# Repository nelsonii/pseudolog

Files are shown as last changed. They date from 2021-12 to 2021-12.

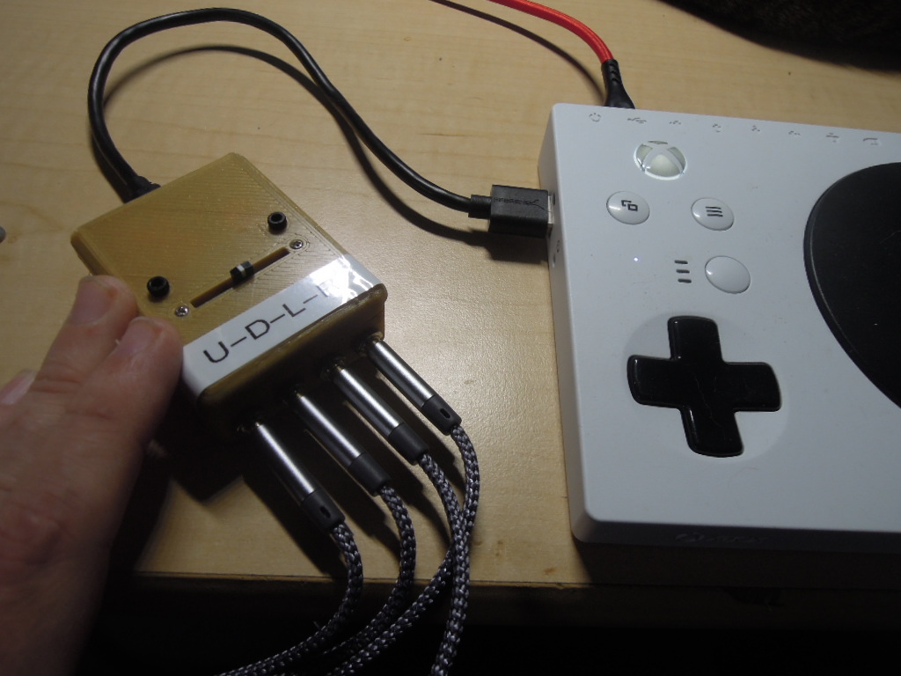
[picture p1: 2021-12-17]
DSCN8653.JPG

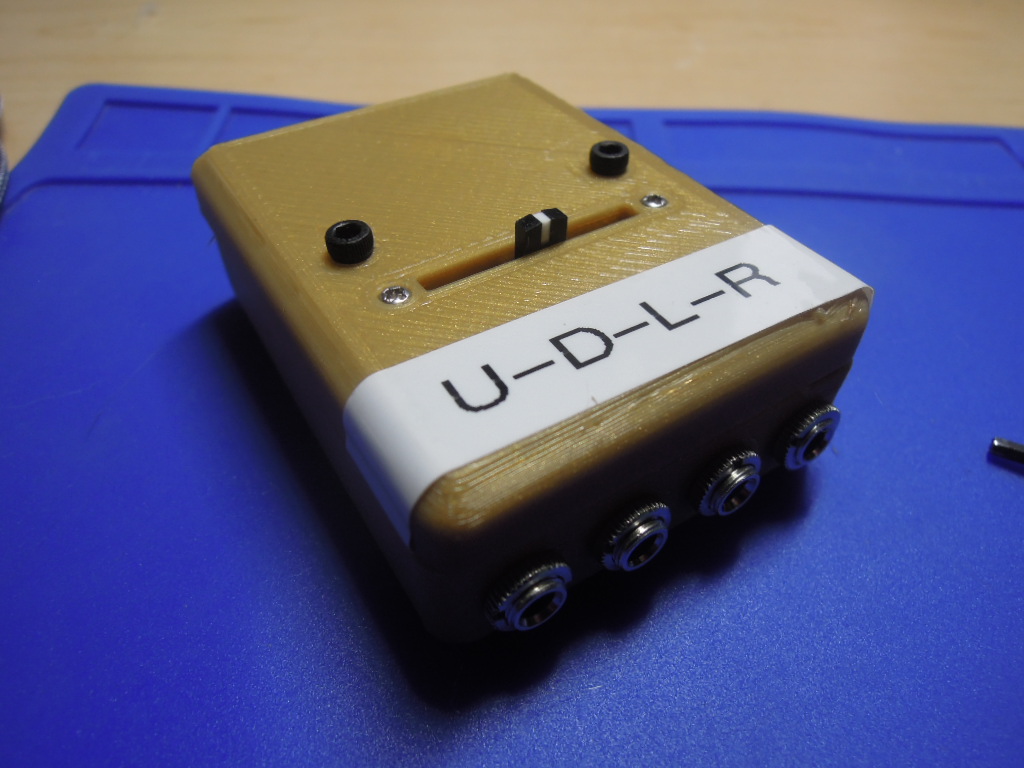
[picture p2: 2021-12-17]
DSCN8651.JPG

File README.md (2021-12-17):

# pseudolog
An Arduino based adapter which converts digital on/off button action to pseudo analog joystick commands.

3D model is in OpenSCAD. If you just want to print the STLs, use the latest verion (alpha order). _TOP should be flipped Y 180 degrees in your slicer.
No supports needed. The cutout circles will print fine.

Sized for an Arduino Pro Micro (Leo). Will also fit a QT PY.

Four jacks get wired to the analog pins. Sensitivity pot to another analog pin. Common power goes to jacks. Common power and Ground go to slide pot. Wiper on slide pot goes to analog pin.

While I'm working on proper schematics, here's the wiring:

Up > A0 (gray wire)
Down > A1 (purple wire)
Left > A2 (orange wire)
Right > A3 (brown wire)

(colors don't matter, but that's what in my photos)

Slide Pot is tied to A10. Slide pot also needs VCC and GND. VCC to pin 1 on pot, GND to pin 3 on pot, A10/signal/wiper to pin 2 on pot.

NeoPixel (optional) tied to pin 6. (Code not yet written.) Also needs VCC and GND.

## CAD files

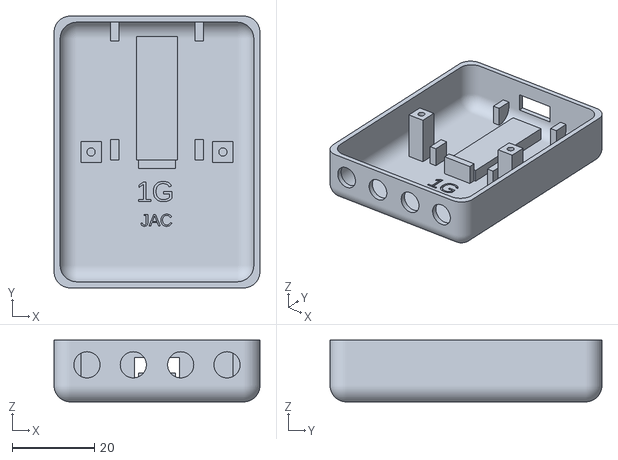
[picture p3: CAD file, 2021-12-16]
SwitchPseudolog_v1G_BOT.stl
50.0 x 66.0 x 15.0

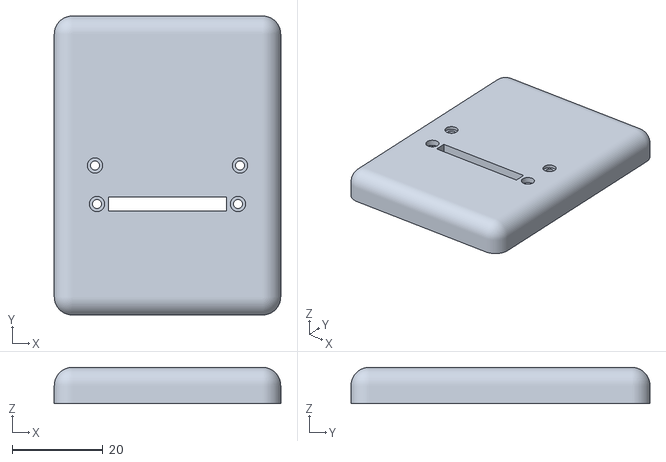
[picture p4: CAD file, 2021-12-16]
SwitchPseudolog_v1E_TOP.stl
50.0 x 66.0 x 8.01

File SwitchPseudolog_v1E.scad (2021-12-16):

include <BOSL/constants.scad>
use <BOSL/shapes.scad>

fileVersion = "1E";

caseWidthX = 50;
caseDepthY = 66;
caseHeightZ = 24;
wallThickness = 3;
overlap = 1; // overlap ensures that subtractions go beyond the edges

includeComponents = false; // optional component models, usually not included in print
  
mountingScrewDiameter = 2.0; // M2 Screw
mountingScrewHeadDiameter = 3.4; // M2 Phillips Head Screw
mountingScrewHeadHeight = 1.6; // M2 Phillips Head Screw

//joyType = "JST6";
//joyType = "DB9";
joyType = "JAC";

emboss = true;
  
$fn=60; //circle smoothness
  
difference(){
  union() {
    difference(){
      //base
      //rounded cuboid is from the BOSL library
      //I'm using p1 setting to zero bottom (z). X/Y are centered on 0,0,0
      color("steelblue")
      cuboid([caseWidthX,caseDepthY,caseHeightZ], fillet=4, 
       p1=[-(caseWidthX/2), -(caseDepthY/2), 0]);
      //subtract out the inner cuboid
      cuboid([caseWidthX-wallThickness,caseDepthY-wallThickness,caseHeightZ-wallThickness], fillet=4, 
       p1=[-((caseWidthX-wallThickness)/2), -((caseDepthY-wallThickness)/2), (wallThickness/2)]);
      if (emboss) {
        //emboss version on inside case
        color("whitesmoke")
         translate([-5, -12, 1])
          linear_extrude(2)
           text(fileVersion, size=5);
        color("whitesmoke")
         translate([-4,-18, 1])
          linear_extrude(2)
           text(joyType, size=3);
        /*
        //emboss port info on outside of case
        color("whitesmoke")
         translate([-7, 25, caseHeightZ - 1]) 
          linear_extrude(2)
           text("USB", size=5);
        color("whitesmoke")
         translate([-20, -28, caseHeightZ - 1]) 
          linear_extrude(2)
           text("U    D    L    R", size=5);
        */
      }
    }//difference (base)

    //riser for micro pro board
    color("purple")
     translate([-5,-2,0])
      cube([10, 30, 5]);
   
    if (joyType=="JST6") {
    //riser for joystick connector (additional support)
    color("darkmagenta")
    translate([-((caseWidthX-wallThickness)/2), 5, 1]) 
        cube([7, 17.5, 4]);
    }
    
    if (joyType=="JAC") {
    //riser for slide pot (additional support)
    color("hotpink")
    translate([-18, -12.5, caseHeightZ-wallThickness-4]) 
        cube([36, 8.25, 6]);
    }
    
    //bumper for micro pro board -- endstop
    color("violet")
     translate([-4.5, -4, 0])  
      cube([9, 2, 7]);
    //bumpers for micro pro board -- lower side
    color("violet")
     translate([-11.25, -2, 0]) 
      cube([2,5,7]);
    color("violet")
     translate([9.25, -2, 0]) 
      cube([2,5,7]);
    //bumpers for micro pro board -- upper side
    color("violet")
     translate([-11.25, 27, 1.5]) 
      cube([2,5,5.5]);
    color("violet")
     translate([9.25, 27, 1.5]) 
      cube([2,5,5.5]);
    
    //case screw mounts
    color("gold")
     translate([-16-2.5, -2.5, 0])
      cube([5,5,caseHeightZ]);
    color("gold")
     translate([+16-2.5, -2.5, 0])
      cube([5,5,caseHeightZ]);

    if (includeComponents) {
      if (joyType=="JST6") {
        //model of connector to joystick
        color("tan")
         translate([-10, -5, 6]) 
          cube([6,18,10]);
      }        
    }//includeComponents
    
  }//union
  
  // Start of Difference stuff ************************************************************

  //USB Micro cable outlet -- chunky cord is 11mm wide and 7mm high.
  color("coral")
   translate([-5.5,30,5.75])
    cube([11, (wallThickness*2), 5]);


  if (joyType=="JST6") {
    //joystick connector
    color("darkorange")
    translate([-((caseWidthX+wallThickness)/2), 5, 5.1]) 
          cube([wallThickness*2, 17.5, 7.0]); 
  }
  if (joyType=="DB9") {
    //joystick connector
    color("darkorange")
    translate([-19.2/2, -((caseDepthY+wallThickness)/2), 5.1]) 
          cube([19.2, wallThickness*2, 10.7]); 
  }


  if (joyType=="JAC") {
    //four switch joystick connection
    color("darkorange")
     translate([-15, -((caseDepthY+wallThickness)/2), 9]) 
      rotate([-90,0,0])
          cylinder(h=wallThickness*2, d=6); 
    color("darkorange")
     translate([+15, -((caseDepthY+wallThickness)/2), 9]) 
      rotate([-90,0,0])
          cylinder(h=wallThickness*2, d=6); 
    color("darkorange")
     translate([-5, -((caseDepthY+wallThickness)/2), 9]) 
      rotate([-90,0,0])
          cylinder(h=wallThickness*2, d=6); 
    color("darkorange")
     translate([+5, -((caseDepthY+wallThickness)/2), 9]) 
      rotate([-90,0,0])
          cylinder(h=wallThickness*2, d=6); 
  }      

if (joyType=="JAC") {
  //slide pot cutout
  color("pink")
   translate([-13, -10, caseHeightZ-wallThickness-5])
    cube([26, 3, wallThickness+overlap+5]);
  //mounting screws
  color("deeppink")
   translate([-15.565, -8.5, caseHeightZ-wallThickness-5])
    cylinder(h=wallThickness+overlap+5, d=2);
  color("deeppink")
   translate([+15.565, -8.5, caseHeightZ-wallThickness-5])
    cylinder(h=wallThickness+overlap+5, d=2);
  //countersinks
  color("hotpink")
   translate([-15.565, -8.5, caseHeightZ-1.5])
    cylinder(h=2+overlap, d=3.4);
  color("hotpink")
   translate([+15.565, -8.5, caseHeightZ-1.5])
    cylinder(h=2+overlap, d=3.4);
}


  //screw hole for case (goes through top of case)
  color("tomato")
   translate([-16, 0, wallThickness])
    cylinder(h=caseHeightZ+overlap, d=mountingScrewDiameter);
  color("tomato")
   translate([+16, -0, wallThickness])
    cylinder(h=caseHeightZ+overlap, d=mountingScrewDiameter);
  
  //countersink
  color("darkorange")
   translate([-16, 0, caseHeightZ-(mountingScrewHeadHeight/2)])
    cylinder(h=mountingScrewHeadHeight+overlap, d=mountingScrewHeadDiameter);
  color("darkorange")
   translate([+16, -0, caseHeightZ-(mountingScrewHeadHeight/2)])  
    cylinder(h=mountingScrewHeadHeight+overlap, d=mountingScrewHeadDiameter);
 
  //-------------------------------------------------------------------------------------------------------

  splitAtZ=15; //actual top of usb opening is 10.75
  
  //remove the top for split
  color("crimson")  translate([-((caseWidthX+overlap)/2),-((caseDepthY+overlap)/2),splitAtZ])  cube([caseWidthX+overlap, caseDepthY+overlap, caseHeightZ+overlap]);
  // ******* OR ******
  //Remove everything but the top
  //color("crimson") translate([-((caseWidthX+overlap)/2),-((caseDepthY+overlap)/2),splitAtZ-caseHeightZ])  cube([caseWidthX+overlap, caseDepthY+overlap, caseHeightZ+overlap]);

  //-------------------------------------------------------------------------------------------------------
  
  
}//difference
  

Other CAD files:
SwitchPseudolog_v1G_TOP.stl
SwitchPseudolog_v1E_BOT.stl
SwitchPseudolog_v1F.scad
SwitchPseudolog_v1G.scad

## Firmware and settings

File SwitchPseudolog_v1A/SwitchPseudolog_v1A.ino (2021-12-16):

//SwitchPseudoLog_v1A

//=================================================================================

#include "Joystick.h"

//=================================================================================

Joystick_ Joystick(JOYSTICK_DEFAULT_REPORT_ID, 
                   JOYSTICK_TYPE_JOYSTICK, 0, 0,
                   true, true, false, false, false, false,
                   false, false, false, false, false);

// constructor: use default id, it's a joystick, there are no buttons,
//              there are no hat buttons, there is an X and Y analog
//              and no other controls.

//=================================================================================

const boolean debug = false; // if true, output info to serial monitor or plotter.
const boolean debugVerbose = false; // if true, output more info to serial monitor.
const boolean debugPlot = false; // if true, output data for plotter/graph viewing.

//=================================================================================

// Joystick pins
#define SW_UP A0
#define SW_DN A1  
#define SW_LT A2
#define SW_RT A3

//pot for adjusting sensitivity
#define SENSE A10

//=================================================================================

// values from switches
long rawLT, rawRT, rawUP, rawDN;

// value from sensitivity pot
long rawSense;
long adjSense;

//=================================================================================

// converted switch values
long adjHorz, adjVert; // data from joystick (cleaned/adjusted)
long mapHorz, mapVert; // mapped values, based on raw
long accHorz, accVert; // acceleration for pseudo analog

// invert if needed
const bool invHorz = false;
const bool invVert = false;

//=================================================================================

// Mapping to XBOX Adaptive Controller
// X and Y will auto map to Axis 0/1 or 2/3 depending on which side you plug
// the joystick into (left=0/1 or right=2/3).

// The XBOX Adapative Controller (XAC) likes joystick values from -127 to + 127
// adjust these min/max based on your upstream device. Same values for both X and Y.
const int joyMin = -127;
const int joyMax = +127;

//=================================================================================

const bool isDigital = true;

//=================================================================================


// set the default min/max values.
// Adjust values based on what you actually get from the stick being used.

int minHorz=0;
int centeredHorz=512;
int maxHorz=1023;

int minVert=0;
int centeredVert=512;
int maxVert=1023;

int threshold = 1023;

//hard limits, to catch out-of-range readings
const int limitMinHorz=0;
const int limitMaxHorz=1023;
const int limitMinVert=0;
const int limitMaxVert=1023;

//=================================================================================


void setup() {

  // Startup the joystick object. 
  Joystick.begin(false); // false indicates that sendState method call required (so we do all changes at once).

  // I'm using Map below, but setting range Just In Case.
  // Also setting Axis to zero at startup.
  Joystick.setXAxisRange(joyMin, joyMax); Joystick.setXAxis(0);
  Joystick.setYAxisRange(joyMin, joyMax); Joystick.setYAxis(0);
  Joystick.sendState();

  // Set U/D/L/R (from joystick) to input
  pinMode(SW_UP, INPUT);
  pinMode(SW_DN, INPUT);
  pinMode(SW_LT, INPUT);
  pinMode(SW_RT, INPUT);
  // Set sensitivity to input
  pinMode(SENSE, INPUT);

  if (debug) { 
    Serial.begin(9600);
    Serial.println("SwitchPseudolog_v1A");
  }

  if (!isDigital) { centerAnalogStick; } //WIP WIP WIP

}//setup


//=================================================================================


void loop() {

  // ----------------------------------------------------

  // Read pot on unit to determine sensitivity (0-1023).
  rawSense = analogRead(SENSE); delay(10);
  if (rawSense==0) {rawSense=1;} // disallow zero

  // Read analog values from input pins.
  rawUP = analogRead(SW_UP); delay(10);
  rawDN = analogRead(SW_DN); delay(10);
  rawLT = analogRead(SW_LT); delay(10);
  rawRT = analogRead(SW_RT); delay(10);

  // Toss out invalid ranges
  if (rawUP<limitMinVert || rawUP>limitMaxVert) {rawUP=centeredVert;}
  if (rawDN<limitMinVert || rawDN>limitMaxVert) {rawDN=centeredVert;}
  if (rawLT<limitMinHorz || rawLT>limitMaxHorz) {rawLT=centeredHorz;}
  if (rawRT<limitMinHorz || rawRT>limitMaxHorz) {rawRT=centeredHorz;}

  if (isDigital) { processDigitalReadings(); }

  // set mins and maxes, if different from previous/default values
  if (adjVert<minVert) {minVert=adjVert;}
  if (adjVert>maxVert) {maxVert=adjVert;}
  if (adjHorz<minHorz) {minHorz=adjHorz;}
  if (adjHorz>maxHorz) {maxHorz=adjHorz;}

  // Map values to a range the XAC likes
  mapVert = map(adjVert, minVert, maxVert, joyMin, joyMax);
  mapHorz = map(adjHorz, minHorz, maxHorz, joyMin, joyMax);

  // Invert value if requested (if "up" should go "down" or "left" to "right")
  if (invVert) {mapVert = -mapVert;}
  if (invHorz) {mapHorz = -mapHorz;}

  // Send the values to the joystick object
  Joystick.setYAxis(mapVert);
  Joystick.setXAxis(mapHorz);

  // Send updated joystick state to HID upstream
  Joystick.sendState();

  // ----------------------------------------------------

  if (debug) {serialDebug();}

}//loop


//=================================================================================


void processDigitalReadings() {

    // if digital switches are used with analog read, they will float
    // look for anything with a full up (1023) on the analog read.

    // The amount of movement is dependent on:
    // (a) how long the switch is held (longer-bigger jumps)
    // (b) multiplied by the sensitivity set (via sliding pot)

    adjSense = rawSense/50; //rawSense will be 1 to 1023 (zero disallowed above)
    if (adjSense<1) {adjSense=1;} // set a lower limit that's not zero
    
    //vertical - up/down
    if (rawUP>=threshold) {
      //toward min 
      if (accVert<threshold) {accVert=accVert+adjSense;} 
      if (adjVert-accVert>minVert) {adjVert=adjVert-accVert;} else {adjVert=minVert;}
      } 
    else if (rawDN>=threshold) {
      //toward max
      if (accVert<threshold) {accVert=accVert+adjSense;} 
      if (adjVert+accVert<maxVert) {adjVert=adjVert+accVert;} else {adjVert=maxVert;}
      }
    else { 
      //reset / re-center
      accVert=0; //reset
      adjVert=centeredVert; // re-center
      }
    
    //horizontal -- left/right
    if (rawLT>=threshold) {
      //toward min   
      if (accHorz<threshold) {accHorz=accHorz+adjSense;} 
      if (adjHorz-accHorz>minHorz) {adjHorz=adjHorz-accHorz;} else {adjHorz=minHorz;}
      } 
    else if (rawRT>=threshold) {
      //toward max
      if (accHorz<threshold) {accHorz=accHorz+adjSense;} 
      if (adjHorz+accHorz<maxHorz) {adjHorz=adjHorz+accHorz;} else {adjHorz=maxHorz;}
      } 
    else {
      //reset / re-center 
      accHorz=0; //reset
      adjHorz=centeredHorz; //re-center
      }

}//processDigitalReadings


//=================================================================================


void centerAnalogStick(){

/*
  // On startup, take some readings from the (hopefully) 
  // centered joystick to determine actual center for X and Y. 
  int iNumberOfSamples = 25;
  long lSampleSumHorz = 0;
  long lSampleSumVert = 0;
  for (int iSample = 1; iSample<=iNumberOfSamples; iSample++) {
    lSampleSumHorz += analogRead(HORZ_PIN); delay(10);
    lSampleSumVert += analogRead(VERT_PIN); delay(10);
  }
  centeredHorz=int(lSampleSumHorz/iNumberOfSamples);
  centeredVert=int(lSampleSumVert/iNumberOfSamples);
 */
 
}//centerAnalogStick


//=================================================================================


void serialDebug() {
  
    if (!debugPlot && debugVerbose) {
        Serial.print("V MinCenMax: ");
        Serial.print(minVert);
        Serial.print(" ");
        Serial.print(centeredVert);
        Serial.print(" ");
        Serial.print(maxVert);
        Serial.print(" ");
        Serial.print("H MinCenMax: ");
        Serial.print(minHorz);
        Serial.print(" ");
        Serial.print(centeredHorz);
        Serial.print(" ");
        Serial.print(maxHorz);
        Serial.print(" ");
        Serial.print("Raw U/D/L/R: ");
        Serial.print(rawUP);
        Serial.print(" ");
        Serial.print(rawDN);
        Serial.print(" ");
        Serial.print(rawLT);
        Serial.print(" ");
        Serial.print(rawRT);
        Serial.print(" ");
        Serial.print("Sense: ");
        Serial.print(rawSense);
        Serial.print(" ");
      }//!debugPlot && debugVerbose

      if (!debugPlot) {
        Serial.print("Acc V/H: ");
        Serial.print(accVert);
        Serial.print(" ");
        Serial.print(accHorz);
        Serial.print(" ");
        Serial.print("Adj Sense: ");
        Serial.print(adjSense);
        Serial.print(" ");
        Serial.print("Adj V/H: ");
        Serial.print(adjVert);
        Serial.print(" ");
        Serial.print(adjHorz);
        Serial.print(" ");
    }//!debugPlot

    if (!debugPlot) {Serial.print("Map V/H: ");}
    
    Serial.print(mapVert);
    if (invVert && !debugPlot) { Serial.print("i"); } // i indicates value was inverted
    Serial.print(" ");
    Serial.print(mapHorz);
    if (invHorz && !debugPlot) { Serial.print("i"); } // i indicates value was inverted 
    Serial.print(" ");
    
    Serial.println();

}//serialDebug

//=================================================================================
